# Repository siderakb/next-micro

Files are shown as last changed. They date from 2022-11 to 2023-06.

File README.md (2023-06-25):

# Next *μ*

**Next *μ*** or **Next Micro** is a Pro Micro/[Elite-C](https://deskthority.net/wiki/Elite-C) compatible ATmega32U4 board, specialized design for keyboards.

It has mid-mount USB Type-C and more available pins (25 pins, all pins of ATmega32U4 except `PE2/HWB`) than both Pro Micro (18 pins) and Elite-C (24 pins).  
The on-board RESET button makes development easier.

> A part of [ErgoSNM keyboard](https://github.com/siderakb/ergo-snm-keyboard) project.  

## Preview

| Front | Back | Layers |
| --- | --- | --- |
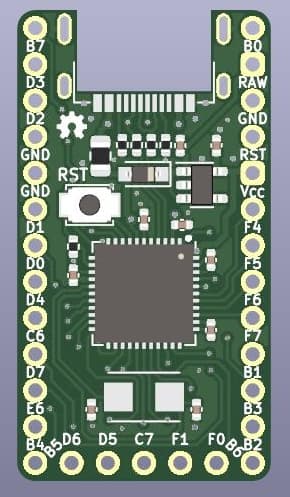
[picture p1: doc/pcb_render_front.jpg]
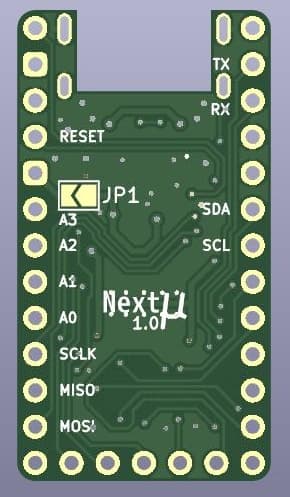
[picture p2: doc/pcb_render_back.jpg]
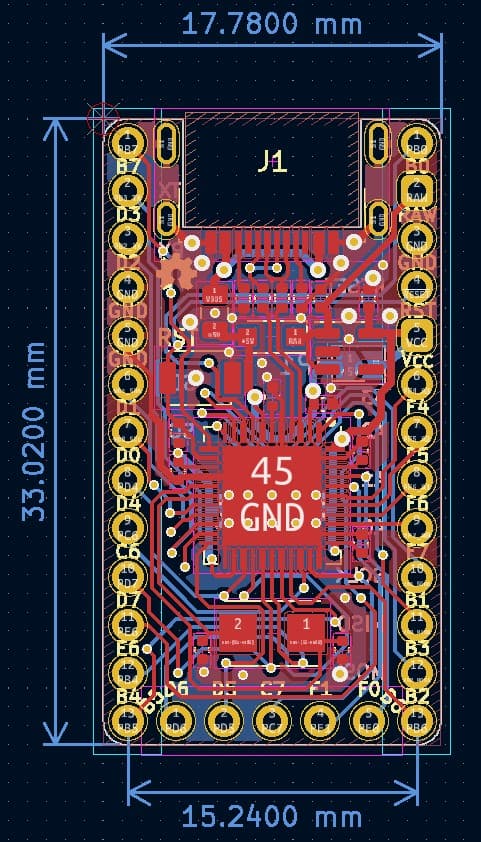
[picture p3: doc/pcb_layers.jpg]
|  |  |  |

## Pinouts
| Func | 32U4  | L <-> R |  32U4 | Func |
| :--- | :---- | :-----: | ----: | ---: |
| | PB7\* | | PB0 | |
| TX | PD3 | | RAW | |
| RX | PD2 | | GND | |
| | GND | | RESET | |
| | GND | | VCC | |
| SDA  | PD1 | | PF4 | A3 |
| SCL  | PD0\* | | PF5 | A2 |
| A6 | PD4 | | PF6 | A1 |
| | PC6\* | | PF7 | A0 |
| A7 | PD7\* | | PB1 | SCLK |
| | PE6 | | PB3 | MISO |
| A8 | PB4 | | PB2 | MOSI |
| A9 | PB5\* | | PB6\* |  A10 |

Bottom row from left to right: PD6, PD5, PC7\*, PF1, PF0.

- The pin marked with `*` can output PWM.
- RAW: LDO Vin pin.

> The pinouts not fully compatible with Elite-C.

## Jumper Config

- JP1: LDO bypass.
  - Open: VCC is 3.3V (LDO Vout).
  - Closed: VCC is 5V (VBUS or RAW). 

## BOM

| Designator  | Value | Footprint |
| --- | --- | --- |
| C1,C2 | 20pF | 0402 (1005 Metric) |
| C3,C6,C7 | 100nF | 0402 (1005 Metric) |
| C4,C5,C8,C9 | 1uF | 0402 (1005 Metric) |
| D1 | B5817 | SOD-323 |
| F1 | 500mA, 6V | 0805 (2012 Metric) |
| J1 | USB_C_Receptacle_USB2.0 | 918-418K2024S40000 |
| R1,R2 | 5.1k | 0402 (1005 Metric) |
| R3,R4 | 22 | 0402 (1005 Metric) |
| R5 | 10k | 0402 (1005 Metric) |
| SW1 | RESET | B3U-1000P |
| U1 | ATmega32U4-M | QFN-44-1EP 7x7mm P0.5mm EP5.2x5.2mm |
| U2 | RT9013-33GB | SOT-23-5 |
| Y1 | 8MHz | 2Pin 5x3.2mm |
> See also [`doc/next-micro_bom.csv`](./doc/next-micro_bom.csv).

There is not designator silkscreen on PCB, please use your browser to open the `ibom.html` file (placed in [release page][release] and [`doc/`](./doc/)) to refer to the placement of the parts, it is generated by [Interactive HTML BOM](https://github.com/openscopeproject/InteractiveHtmlBom) plugin.

## PCBA

The BOM and CPL files for PCBA are placed in the [`doc/`](./doc/) folder and [release page][release].

## Board Characteristics

- Copper layer count: 2
- Board thickness: 1.6 mm
- Board overall dimensions: 17.78 x 33.02 mm (0.7 x 1.3 inch)
- Min track/spacing: 0.13 mm / 0.13 mm
- Min hole diameter: 0.3 mm
- Castellated pads: No
- Edge card connectors: No
- Plated board edge: No

## Disclaimer

These files without warranty of any kind, use at your own risk, it is recommended to check yourself before manufacture.

For the full statement, please see [LICENSE](./LICENSE).

[release]: https://github.com/ziteh/next-micro/releases

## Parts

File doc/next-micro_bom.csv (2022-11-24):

Comment | Designator | Footprint | JLCPCB Part #
20pF | C1,C2 | Capacitor_SMD:C_0402_1005Metric | C1554
100nF | C3,C6,C7 | Capacitor_SMD:C_0402_1005Metric | C307331
1uF | C4,C5,C8,C9 | Capacitor_SMD:C_0402_1005Metric | C52923
B5817 | D1 | Diode_SMD:D_SOD-323 | C123899
500mA, 6V | F1 | Fuse:Fuse_0805_2012Metric | C269104
USB_C_Receptacle_USB2.0 | J1 | next_micro:USB Type-C Mid-Mount Receptacle 16P | C168688
5.1k | R1,R2 | Resistor_SMD:R_0402_1005Metric | C25905
22 | R3,R4 | Resistor_SMD:R_0402_1005Metric | C25092
10k | R5 | Resistor_SMD:R_0402_1005Metric | C25744
RESET | SW1 | Button_Switch_SMD:SW_SPST_B3U-1000P | C231329
ATmega32U4-M | U1 | Package_DFN_QFN:QFN-44-1EP_7x7mm_P0.5mm_EP5.2x5.2mm | C112161
RT9013-33GB | U2 | Package_TO_SOT_SMD:SOT-23-5 | C47773
8MHz | Y1 | Crystal:Crystal_SMD_Qantek_QC5CB-2Pin_5x3.2mm | C115962

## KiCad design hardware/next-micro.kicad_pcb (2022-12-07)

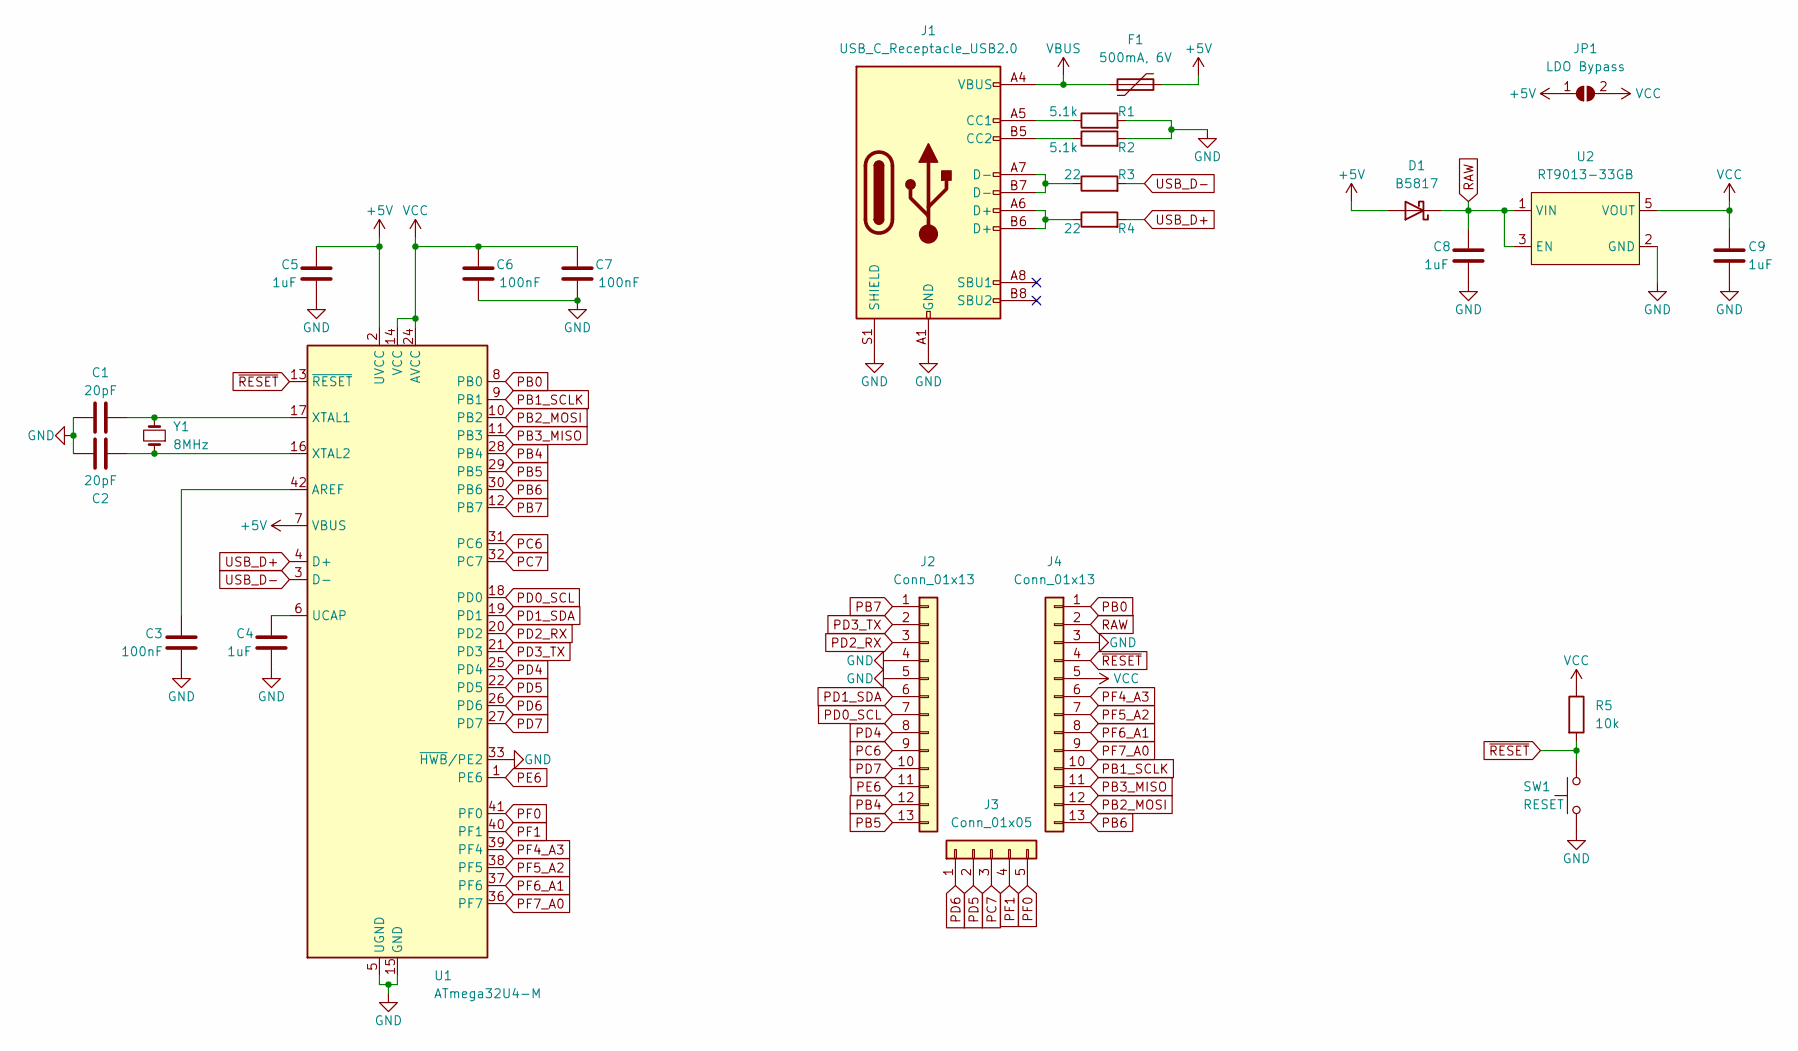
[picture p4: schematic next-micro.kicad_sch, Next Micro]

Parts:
C1, C2: 20pF; C_0402_1005Metric; MFR. Part # 0402CG200J500NT; JLCPCB Part # C1554
C3, C6, C7: 100nF; C_0402_1005Metric; MFR. Part # CL05B104KB54PNC; JLCPCB Part # C307331
C4, C5, C8, C9: 1uF; C_0402_1005Metric; MFR. Part # CL05A105KA5NQNC; JLCPCB Part # C52923
D1: B5817; D_SOD-323_HandSoldering; MFR. Part # B5817WS; JLCPCB Part # C123899
F1: 500mA, 6V; Fuse_0805_2012Metric; MFR. Part # SMD0805B050TF; JLCPCB Part # C269104
J1: USB_C_Receptacle_USB2.0; USB Type-C Mid-Mount Receptacle 16P; MFR. Part # 918-418K2024S40000; JLCPCB Part # C168688
J2, J4: Conn_01x13; PinHeader_1x13_P2.54mm_Vertical
J3: Conn_01x05; PinHeader_1x05_P2.54mm_Vertical
JP1: SolderJumper_2_Open; SolderJumper-2_P1.3mm_Open_TrianglePad1.0x1.5mm
R1, R2: 5.1k; R_0402_1005Metric; MFR. Part # 0402WGF5101TCE; JLCPCB Part # C25905
R3, R4: 22; R_0402_1005Metric; MFR. Part # 0402WGF220JTCE; JLCPCB Part # C25092
R5: 10k; R_0402_1005Metric; MFR. Part # 0402WGF1002TCE; JLCPCB Part # C25744
SW1: RESET; SW_SPST_B3U-1000P; MFR. Part # B3U-1000P; JLCPCB Part # C231329
U1: ATmega32U4-M; QFN-44-1EP_7x7mm_P0.5mm_EP5.2x5.2mm; MFR. Part # ATMEGA32U4-MU; JLCPCB Part # C112161
U2: RT9013-33GB; SOT-23-5; MFR. Part # RT9013-33GB; JLCPCB Part # C47773
Y1: 8MHz; Crystal_SMD_Qantek_QC5CB-2Pin_5x3.2mm; MFR. Part # X50328MSB2GI; JLCPCB Part # C115962

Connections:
+5V: C5.1, D1.2 (A), F1.2, JP1.1 (A), U1.2 (UVCC), U1.7 (VBUS)
GND: C1.1, C2.1, C3.1, C4.2, C5.2, C6.1, C7.1, C8.2, C9.2, J1.A1 (GND), J1.A12 (GND), J1.B1 (GND), J1.B12 (GND), J1.S1 (SHIELD), J2.4, J2.5, J4.3, R1.2, R2.2, SW1.1, U1.5 (UGND), U1.15 (GND), U1.23 (GND), U1.33 (~HWB/PE2), U1.35 (GND), U1.43 (GND), U1.45 (GND), U2.2 (GND)
unnamed: C1.2, U1.17 (XTAL1), Y1.2
unnamed: C2.2, U1.16 (XTAL2), Y1.1
unnamed: C3.2, U1.42 (AREF)
unnamed: C4.1, U1.6 (UCAP)
unnamed: J1.A5 (CC1), R1.1
unnamed: J1.A6 (D+), J1.B6 (D+), R4.1
unnamed: J1.A7 (D-), J1.B7 (D-), R3.1
unnamed: J1.B5 (CC2), R2.1
PB0: J4.1, U1.8 (PB0)
PB1_SCLK: J4.10, U1.9 (PB1)
PB2_MOSI: J4.12, U1.10 (PB2)
PB3_MISO: J4.11, U1.11 (PB3)
PB4: J2.12, U1.28 (PB4)
PB5: J2.13, U1.29 (PB5)
PB6: J4.13, U1.30 (PB6)
PB7: J2.1, U1.12 (PB7)
PC6: J2.9, U1.31 (PC6)
PC7: J3.3, U1.32 (PC7)
PD0_SCL: J2.7, U1.18 (PD0)
PD1_SDA: J2.6, U1.19 (PD1)
PD2_RX: J2.3, U1.20 (PD2)
PD3_TX: J2.2, U1.21 (PD3)
PD4: J2.8, U1.25 (PD4)
PD5: J3.2, U1.22 (PD5)
PD6: J3.1, U1.26 (PD6)
PD7: J2.10, U1.27 (PD7)
PE6: J2.11, U1.1 (PE6)
PF0: J3.5, U1.41 (PF0)
PF1: J3.4, U1.40 (PF1)
PF4_A3: J4.6, U1.39 (PF4)
PF5_A2: J4.7, U1.38 (PF5)
PF6_A1: J4.8, U1.37 (PF6)
PF7_A0: J4.9, U1.36 (PF7)
RAW: C8.1, D1.1 (K), J4.2, U2.1 (VIN), U2.3 (EN)
USB_D+: R4.2, U1.4 (D+)
USB_D-: R3.2, U1.3 (D-)
VBUS: F1.1, J1.A4 (VBUS), J1.A9 (VBUS), J1.B4 (VBUS), J1.B9 (VBUS)
VCC: C6.2, C7.2, C9.1, J4.5, JP1.2 (B), R5.1, U1.14 (VCC), U1.24 (AVCC), U1.34 (VCC), U1.44 (AVCC), U2.5 (VOUT)
~RESET: J4.4, R5.2, SW1.2, U1.13 (~RESET)

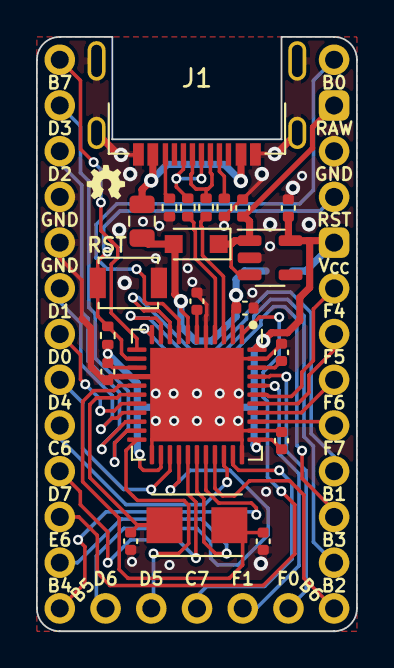
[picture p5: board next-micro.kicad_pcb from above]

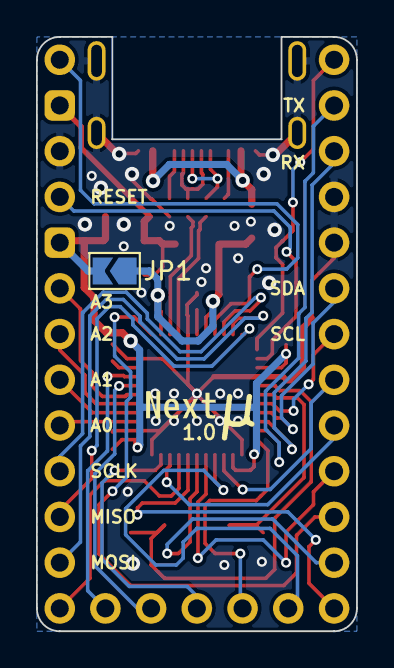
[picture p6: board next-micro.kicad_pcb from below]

Board: 2 copper layers, 17.8 x 33.0 mm, 26 parts (4 on the bottom side), 41 nets.

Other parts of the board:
kibuzzard-637F2329: G***; kibuzzard-637F2329

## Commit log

2022-11-24 init commit
    [next-micro.kicad_pcb, next-micro.kicad_sch]
2022-11-24 Add PCBA files and move files
    [next-micro.kicad_pcb, next-micro.kicad_sch, next-micro_bom.csv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]
2022-12-07 Replace D1 footprint to hand soldering version
    [next-micro.kicad_pcb, next-micro.kicad_sch]
2022-12-07 Update CPL
    [next-micro_cpl.csv]
2022-12-07 Update date
    [next-micro.kicad_pcb, next-micro.kicad_sch]
2023-04-29 Add footprint library path table

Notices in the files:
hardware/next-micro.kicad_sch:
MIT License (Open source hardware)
